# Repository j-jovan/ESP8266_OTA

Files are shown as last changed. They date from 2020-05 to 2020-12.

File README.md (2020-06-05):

# SHK_Sterilizator_Prostorije_ESP32_OTA
## Srbija Hakuje Koronu Hakaton  
Kontrolna kutija za sterilizator prostorije

Komponente:  
ESP32 DevKitv1
PMS7003  
SD Card Reader  
Display 20x4 with I2C Adapter  
Servo Motor  
2x Senzori Pritiska  
3x 12v Releji (Svetla, motor i rezervni)  

Dodatne biblioteke:
https://github.com/nhatuan84/esp32-micro-sdcard
https://github.com/fdebrabander/Arduino-LiquidCrystal-I2C-library

Wiring  
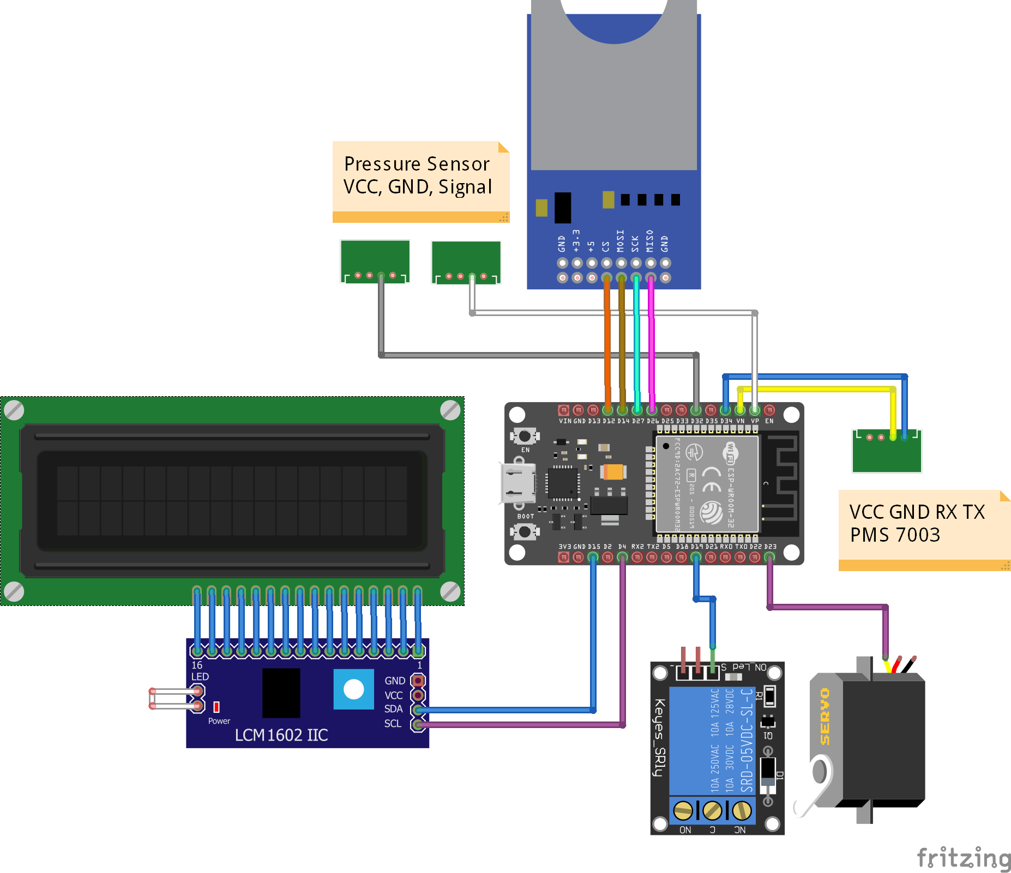
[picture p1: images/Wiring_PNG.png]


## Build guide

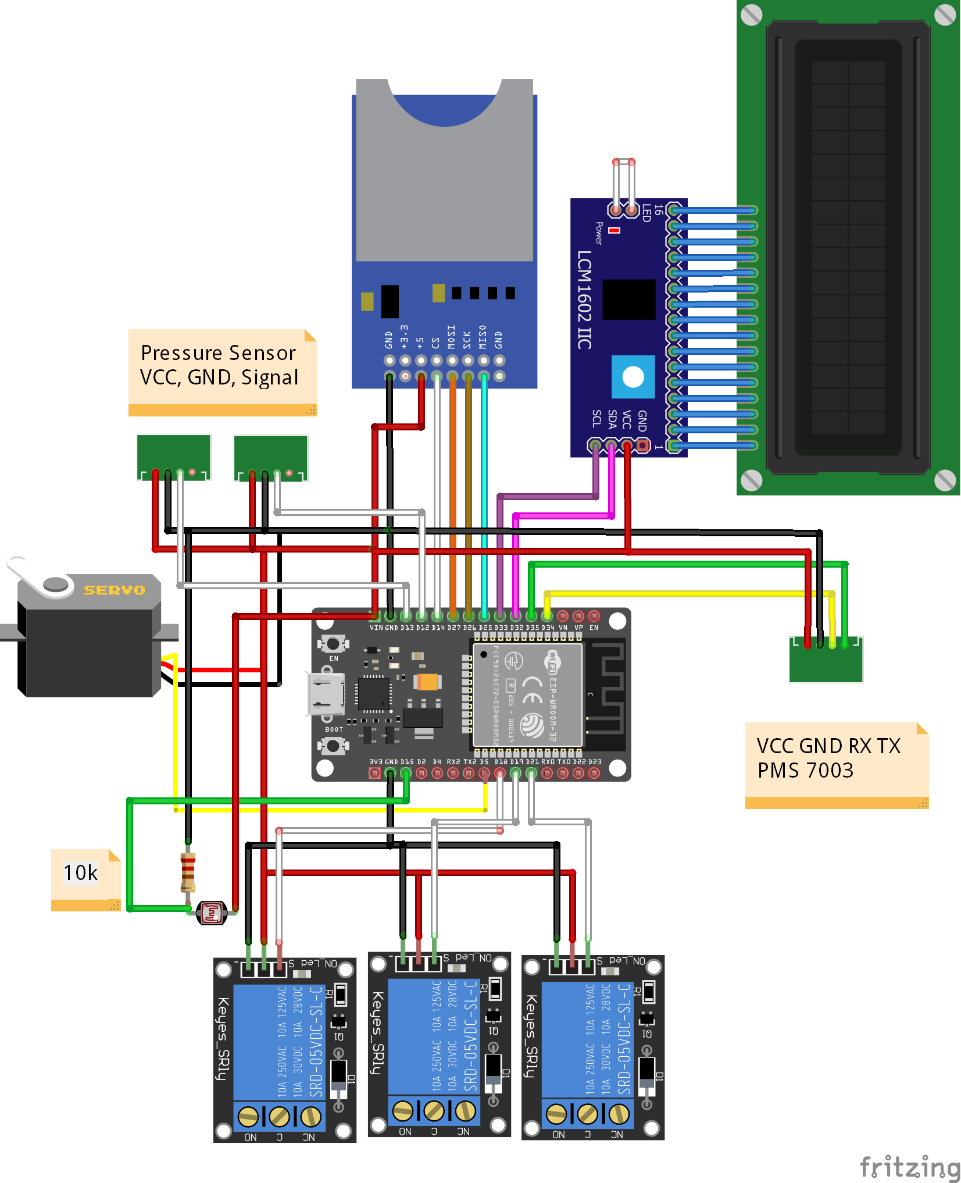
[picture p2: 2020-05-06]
images/Wiring_bb.png

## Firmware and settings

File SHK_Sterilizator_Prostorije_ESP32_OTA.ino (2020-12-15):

/*
    Srbija Hakuje Koronu
    Sterilizator Prostorije

    Kod napisan za potrebe Sterilizatora prostorije
    Razvijen na "Srbija Hakuje Koronu" Hakatonu
    Beograd, Jun 2020

    ESP board link:
    https://dl.espressif.com/dl/package_esp32_index.json, http://arduino.esp8266.com/stable/package_esp8266com_index.json


    Koriscene biblioteke:
    https://github.com/fu-hsi/PMS
    https://github.com/nhatuan84/esp32-micro-sdcard
    https://github.com/adafruit/Adafruit_Sensor
    https://github.com/adafruit/Adafruit_BME280_Library
    https://github.com/fdebrabander/Arduino-LiquidCrystal-I2C-library

    Koriscene elektronske komponente:
    1. ESP32 DevKit V1
    2. BMP280 3.3v x2
    3. LCD Display 20x4
    4. PMS 7003 Particle Sensor
    5. MicroSD Card Reader i microSD kartica (256mb minimum)
    6. Motor CBM/2-146/180 - 380W (1090m3/H, 2000 RPM)
    7. UV Sijalice (Germicidne) x6
    8. Razna sitna elektronika i plasticni delovi

    Dodatne komponente:
    9. HEPA filter
    10. Predfilter x2 (Predfilteri upijaju krupnije cestice kako bi HEPA trajao duze)

    Opis uredjaja:
    Uredjaj je podeljen na dve komore (gornju i donju) pomocu dva predfiltera (10) i HEPA filtera (9).
    Vazduh ulazi kroz resetku na gornjoj komori, prolazi kroz dva predfiltera (10) i onda ga UV (7) sterilise.
    Nakon toga prolazi kroz HEPA filter (9), pa sledi jos jedna sterilizaciju UV (7) lampama pre napustanja uredjaja.
    U donjoj komori uredjaja se nalazi motor (6) koji uvlaci provlaci vazduh kroz ceo uredjaj.

    Info:
    Prvobitni plan je bio da koristimo cip iz Arduino Uno ili Arduino Pro Mini/Nano, ali nije bilo dovoljno memorije za kod, te smo uzeli ESP32
    LCD Displej prikazuje podatke iz uredjaja korisnicima
    Podaci iz senzora cestica se cuvaju u micoSD kartici, kao i radno vreme uredjaja
    Senzor pritiska prati pritisak u dve komore i obavestava korisnika ukoliko je razlika prevelika, jer to znaci da je vreme za zamenu filtera.
    Radni vek UV lampi je 50.000 sati.



*/

#include <Wire.h>
#include "PMS.h"
#include <mySD.h>

#define PMS_READ_INTERVAL 3

#define DEBUGG
#ifdef DEBUGG
// #define DPRINT(x) Serial.print(x)      //Uncomment to enable debugging
// #define DPRINTLN(x) Serial.println(x)  //Uncomment to enable debugging
// #elif
#define DPRINT(x) ;
#define DPRINTLN(x) ;
#endif

int relejUV = 19;
int prekidac = 33;
bool ukljuciUredjaj = false;

void setup(void) {
  // https://9gag.com/gag/a9nbgyW
  Serial.begin(115200);
  pinMode(relejUV, OUTPUT);
  pinMode(prekidac, INPUT);
  LCD_Setup();
  PMS7003_Setup();
  OTA_Setup();
  LCD_SHK_Message();
  init_SDCard();
  ukljuciUV();
  BMP280_Setup();
}

void loop(void) {

  PMS::DATA data;
  unsigned int seconds;
  unsigned int minutes;
  static unsigned int SDMinutesWrite = 1;
  static unsigned int PMSMinutesOn = 0;
  static unsigned int PMSMinutesRead = 1;
  static unsigned int PressureMinutesRead = 1;
  timer(seconds, minutes);



  if (minutes == PMSMinutesOn) {
    PMS7003WakeUp();
    PMSMinutesOn += PMS_READ_INTERVAL;
  }
  if (minutes == PMSMinutesRead) {
    PMS7003ReadData(data);
    PMS7003Sleep();
    LCD_PMS7003(data);
    upisiPMSData(data);
    PMSMinutesRead += PMS_READ_INTERVAL;
  }

  if (minutes == SDMinutesWrite) {
    upisiNaKarticu();
    SDMinutesWrite++;
    PMS7003_Setup();
    LCD_PMS7003(data);
    BMP280_Setup();
  }

  //Proveri i postavi snagu motora na svakih 30 sekundi
  if (seconds % 30 == 0) {
    motorDacMap();
  }

  OTAHandleClient();

  // BMP280_Loop();
  DPRINTLN("Razlika pritiska je: ");
  DPRINTLN(vratiRazlikuPritiska());
  if (minutes == PressureMinutesRead) {
    if (vratiRazlikuPritiska() > 10) {
      LCD_Filteri();
    }
  }
  delay(500);
  DPRINTLN("--------------------");
}

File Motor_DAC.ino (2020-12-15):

#define DAC1 25
int serialRead;

// Motor je podesen da prati razliku pritiska u komorama
// I da smanjuje snagu sa porastom razlike pritiska
// Snaga motora je regulisana pomocu diaka/triaka kojim upravljaju LE dioda i fotootpornik.

// Rucno izracunate vrednosti
int snagaMotora[7] = {1, 153, 154, 155, 156, 158, 200};

void motorDacMap() {
  int val = vratiRazlikuPritiska();
  val = map(val, 0, 30, 6, 1);  // Ako razlika 0, snaga motora 7, ako razlika
  dacWrite(DAC1, snagaMotora[val]);

  DPRINTLN("************************* ");
  DPRINTLN("Snaga motora je: ");
  DPRINT(val);
  DPRINTLN("************************* ");
}


// Provera rada motora sa rucnim unosenjem vrednosti preko Serial Monitora
void motorDacTestManual() {
  if (Serial.available() > 0) {
    int serialRead = Serial.parseInt();
    DPRINTLN("----------------------------");
    DPRINTLN("Unesi vrednost");

    if (serialRead == 0) {
      // Nakon sto Serial.available procita i ispise vrednost
      // Uvek stavi da je vrednost open 0
    }
    else {
      DPRINT("Uneta vrednost je: ");
      DPRINTLN(serialRead);
      dacWrite(DAC1, serialRead);
      DPRINTLN("----------------------------");
    }
  }
}

// Automatska provera rada motora tako sto ESP32 sam pojaca snagu motora od minimuma do maksimuma
void motorDacTestAuto() {
  // 255 = 3.3V / 128 = 1.65V
  for (int i = 0; i <= 255; i++) {
    dacWrite(DAC1, i);
    delay(1000);
  }
}

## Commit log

2020-05-03 Dodat PMS7003 i wiring dijagram
    [Wiring.fzz]
2020-05-03 Dodat wiring
    [Wiring.fzz]
2020-05-05 Updated code and wiring
    [Wiring.fzz]
2020-05-05 Update wiring
2020-05-06 Updated wiring
    [Wiring.fzz]
2020-05-09 Updat and bugfix LCD, PMS, SD
    [LCDisplej.ino, PMS7003.ino, SDCard.ino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]
2020-05-09 Updated SD card and timers
2020-05-10 Added servo, update rest
2020-05-10 Updated wiring and code
    [Wiring.fzz]
2020-05-12 Update servo and relay
2020-06-02 Update motor PWM
2020-06-03 Updated sdcard code to match PCB
2020-06-03 Preradjena timer funkcija
2020-06-05 Dodata kontrola motora DAC pinom
2020-06-11 Updated sensor and general stuff
2020-06-30 Updated code, fixed motor and BPM280
    [Motor_DAC.ino, OTAWeb.ino, PMS7003.ino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]
2020-12-14 Bug sa prekidacem na 33
    [LCDisplej.ino, Motor_DAC.ino, SHK_Sterilizator_Prostorije_ESP32_OTA.ino]
